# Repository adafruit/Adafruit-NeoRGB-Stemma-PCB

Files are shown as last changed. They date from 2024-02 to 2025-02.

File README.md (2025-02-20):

## Adafruit NeoRGB Stemma - NeoPixel to RGB PWM LEDs and Strips - STEMMA JST PH 2mm PCB

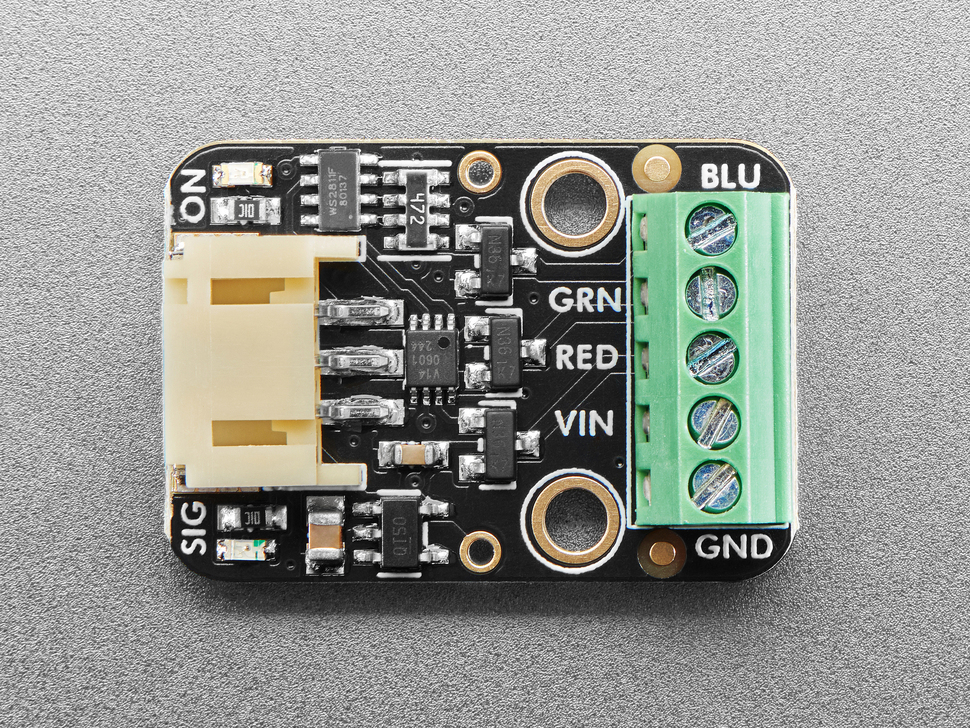
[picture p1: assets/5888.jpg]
<a href="http://www.adafruit.com/products/5888"><br/>
Click here to purchase one from the Adafruit shop</a>

PCB files for the Adafruit NeoRGB Stemma - NeoPixel to RGB PWM LEDs and Strips - STEMMA JST PH 2mm. 

Format is EagleCAD schematic and board layout
* https://www.adafruit.com/product/5888

### Description

Whenever we're working with 'true analog' LED strips, that have 1-3 channels of RGB or White LEDs, we wish we had already invented to make wiring them easier: controlling these strips takes a bit of wiring since they almost always need 12VDC and driver FETs. Now, we've finally created the Adafruit NeoRGB Stemma board - which will make our lives easier, and maybe even some customer's too!

The NeoRGB is a no-soldering, plug-and-play STEMMA board with a 2mm JST PH connector on one end, and a 5-pin 0.1" screw terminal block on the other. It can convert standard 800KHz NeoPixel signal using a WS2811F chip to AO3406 N-channel FETs that are high efficiency and can sink a chunk of current - 3 Amps a piece with 50milliOhm Ron!

Basically, this means that you can treat any PWM-able common-anode RGB LED strip or LED as a single NeoPixel, at up to 16V and 3 Amps per channel. Perfect for large analog LEDs or arrays, LED strips, even ones that are not RGB, such as controlling 3 independent single-channel LEDs or strips. Note that the WS2811 bare chips don't support 4 channels, so this won't work on RGBW strips.

Usage is easy. First you'll need a 2mm JST PH cable, such as this one with pins. Then pick one of two powering options

If you are using less than 2A of current total across all 3 channels:

	1. Connect the white wire to your NeoPixel-compatible signal, 3 or 5V logic.
	2. Connect the red wire to 3-16VDC, this will power the LED strip
	3. Connect the black ground wire to your microcontroller and power supply shared ground
	
If you are using more than 2A of current total across all 3 channels, you'll need to wire the power supply to the terminal block since JST PH connectors are only rated for 2A.

	1. Connect the white wire to your NeoPixel-compatible signal, 3 or 5V logic.
	2. Connect your 3-16V power supply positive pin to the V+ to the terminal block, keep the red wire from being used by taping it or cutting it off.
	3. Connect the 3-16V power supply ground pin to the GND on the terminal block
	4. Connect the black wire as a 'reference' ground to your microcontroller that is providing the NeoPixel signal

An onboard green ON LED will let you know that it is powered correctly, and a red Signal LED will lightly blink when data is sent on the Signal line. If you need to chain more than one, or want to connect some other NeoPixels to the output, there's a pin for the Output signal on the board.

<b>Revision History:</b>

* As of February 13, 2025 - We've updated this design to add a built-in level shifter so it will work flawlessly with 3V or 5V NeoPixel signals.

### License

Adafruit invests time and resources providing this open source design, please support Adafruit and open-source hardware by purchasing products from [Adafruit](https://www.adafruit.com)!

Designed by Limor Fried/Ladyada for Adafruit Industries.

Creative Commons Attribution/Share-Alike, all text above must be included in any redistribution. 
See license.txt for additional details.

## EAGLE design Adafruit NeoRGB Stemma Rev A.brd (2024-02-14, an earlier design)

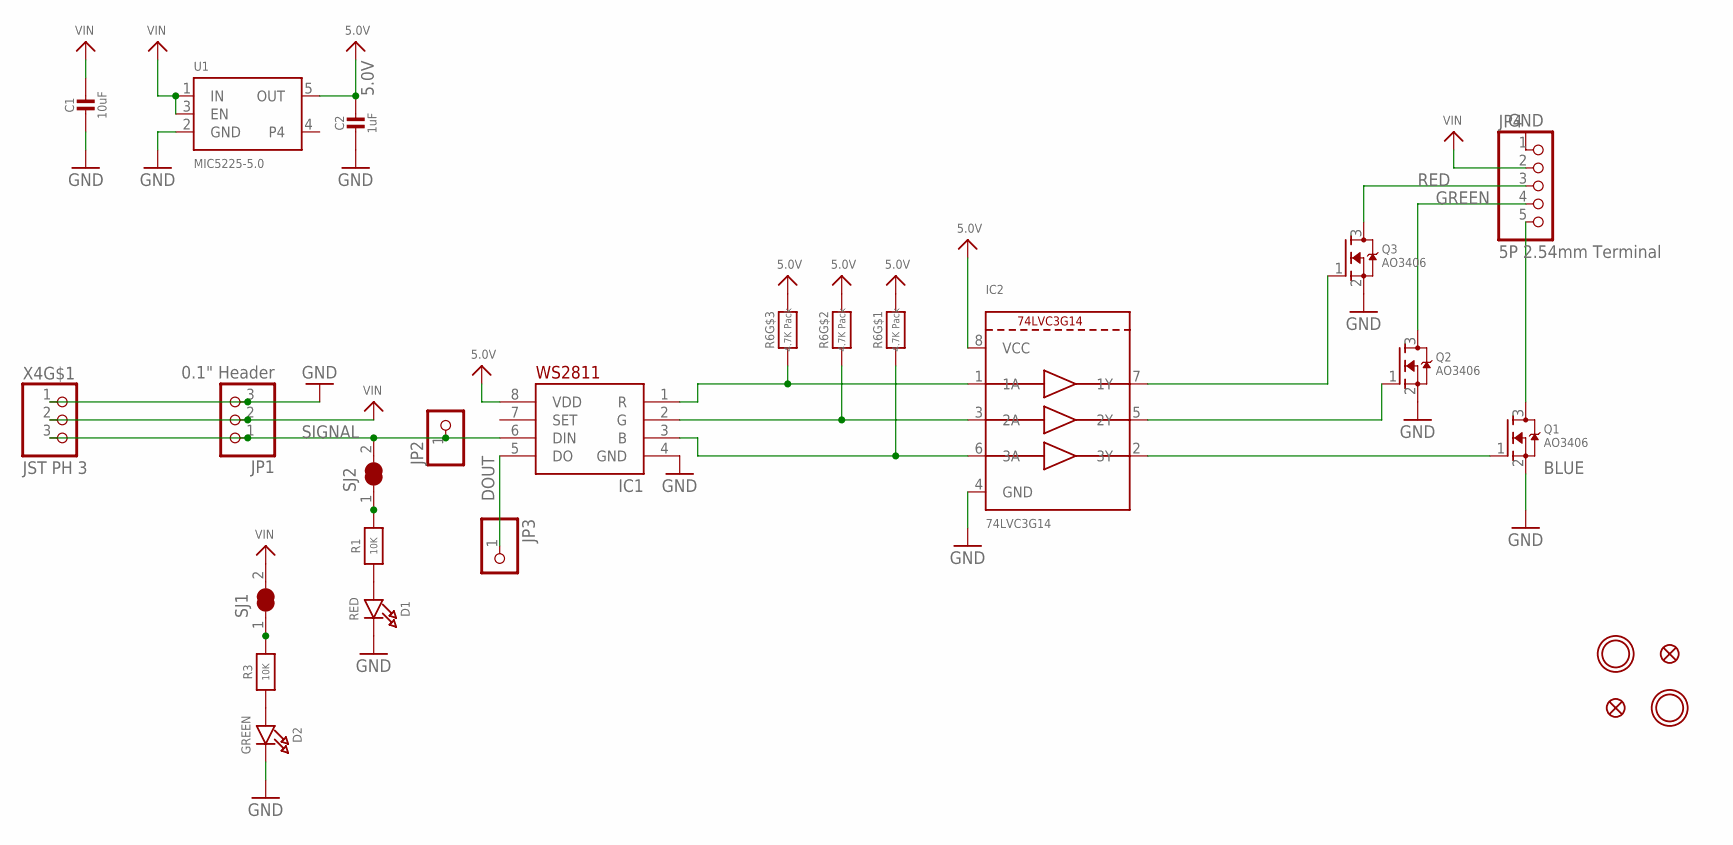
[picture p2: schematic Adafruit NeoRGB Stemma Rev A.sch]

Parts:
C1: 10uF; 0805-NO
C2: 1uF; 0603-NO
D1: RED; CHIPLED_0603_NOOUTLINE
D2: GREEN; CHIPLED_0603_NOOUTLINE
FID2, FID3: FIDUCIAL_1MM
IC1: WS2811F; FSOP-8
IC2: 74LVC3G14; VFSOP-8
JP1: 0.1" Header; 1X03_OVAL
JP2, JP3: HEADER-1X1ROUND; 1X01_ROUND
JP4: 5P 2.54mm Terminal; 1X05_2.54MMTERMINAL
Q1, Q2, Q3: AO3406; SOT23-WIDE
R1, R3: 10K; 0603-NO
R6: 4.7K Pack; RESPACK_4X0603
SJ1, SJ2: SOLDERJUMPER_CLOSED; SOLDERJUMPER_CLOSEDWIRE
U1: MIC5225-5.0; SOT23-5; JLC_ROTATION 0
U$1, U$8: MOUNTINGHOLE2.5; MOUNTINGHOLE_2.5_PLATED
X4: JST PH 3; JSTPH3

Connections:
5.0V: C2.1, IC1.8 (VDD), IC2.8 (VCC), R6.6 (2), R6.7 (2), R6.8 (2), U1.5 (OUT)
BLUE: JP4.5, Q1.3 (D)
DOUT: IC1.5 (DO), JP3.1
GND: C1.2, C2.2, D1.C, D2.C, IC1.4 (GND), IC2.4 (GND), JP1.3, JP4.1, Q1.2 (S), Q2.2 (S), Q3.2 (S), U1.2 (GND), X4.1
GREEN: JP4.4, Q2.3 (D)
unnamed: R3.2, SJ1.1
unnamed: D1.A, R1.1
unnamed: R1.2, SJ2.1
unnamed: IC2.2 (3Y), Q1.1 (G)
unnamed: IC2.5 (2Y), Q2.1 (G)
unnamed: IC2.7 (1Y), Q3.1 (G)
unnamed: IC1.1 (R), IC2.1 (1A), R6.3 (1)
unnamed: IC1.2 (G), IC2.3 (2A), R6.2 (1)
unnamed: IC1.3 (B), IC2.6 (3A), R6.1
unnamed: D2.A, R3.1
RED: JP4.3, Q3.3 (D)
SIGNAL: IC1.6 (DIN), JP1.1, JP2.1, SJ2.2, X4.3
VIN: C1.1, JP1.2, JP4.2, SJ1.2, U1.1 (IN), U1.3 (EN), X4.2

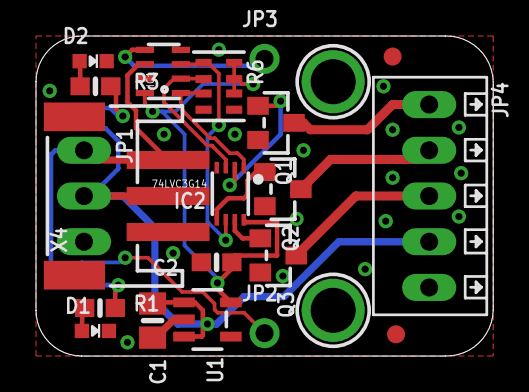
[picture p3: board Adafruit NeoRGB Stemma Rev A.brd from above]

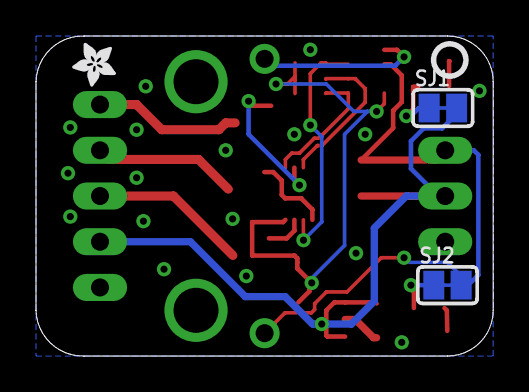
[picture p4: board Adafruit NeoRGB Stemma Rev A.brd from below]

Board: 2 copper layers, 25.4 x 17.8 mm, 45 parts (16 on the bottom side), 18 nets.

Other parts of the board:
E$1: ADAFRUIT_2.5MM
PLABEL0: PLABEL0
PLABEL1: PLABEL1
PLABEL2: PLABEL2
PLABEL3: PLABEL3
PLABEL4: PLABEL4
PLABEL5: PLABEL5
PLABEL6: PLABEL6
PLABEL7: PLABEL7
PLABEL8: PLABEL8
PLABEL9: PLABEL9
PLABEL10: PLABEL10
PLABEL11: PLABEL11
PLABEL12: PLABEL12
PLABEL13: PLABEL13
PLABEL14: PLABEL14
PLABEL15: PLABEL15
PLABEL16: PLABEL16
PLABEL17: PLABEL17
PLABEL18: PLABEL18
U$5: PCBFEAT-REV-040

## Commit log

2025-02-20 adding rev B
    [Adafruit NeoRGB Stemma Rev B.brd, Adafruit NeoRGB Stemma Rev B.sch]
2025-02-20 rev a label
    [Adafruit NeoRGB Stemma Rev A.brd, Adafruit NeoRGB Stemma Rev A.sch]

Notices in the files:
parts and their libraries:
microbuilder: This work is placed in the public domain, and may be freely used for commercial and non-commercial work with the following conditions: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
